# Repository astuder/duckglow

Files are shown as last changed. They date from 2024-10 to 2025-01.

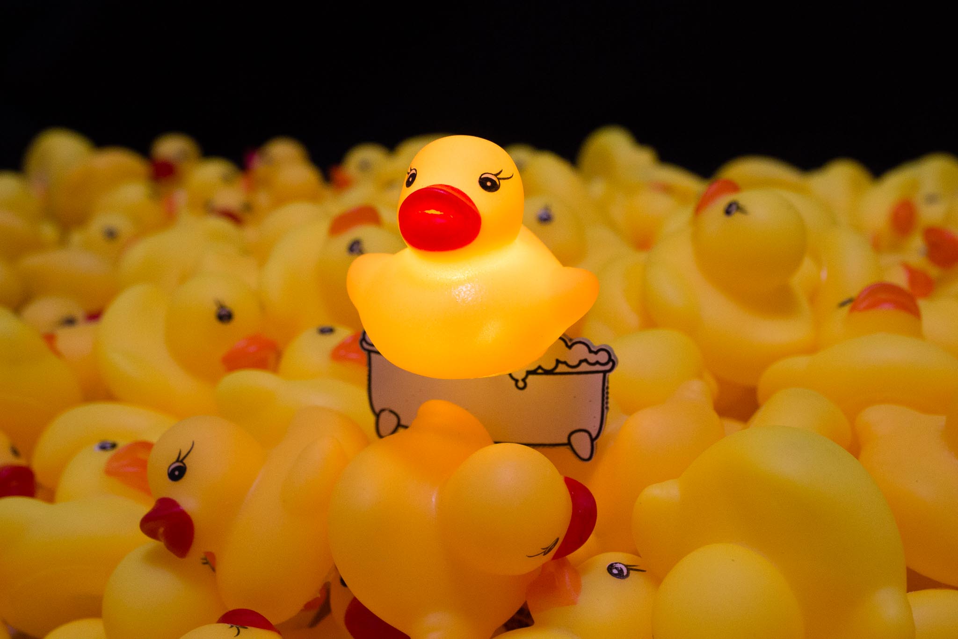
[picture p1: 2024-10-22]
pictures/duckbath.jpg

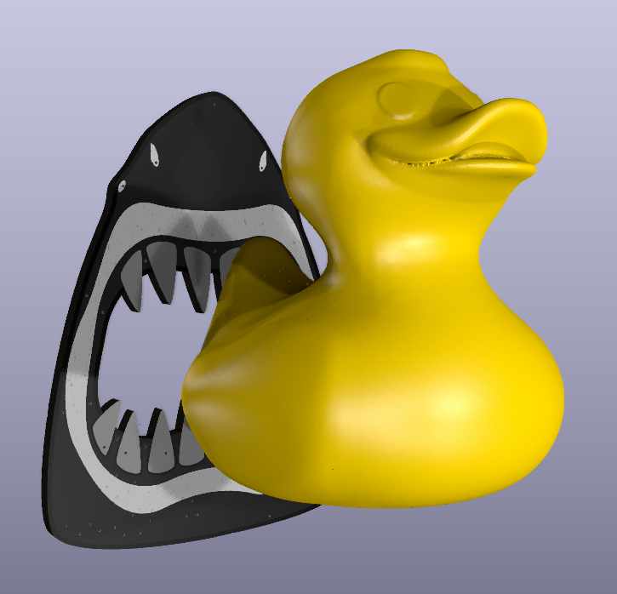
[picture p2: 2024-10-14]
pictures/duckjaws-render.png

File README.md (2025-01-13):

# duckGLOW SAO

duckGLOW is an SAO with a glowing rubber duck, lit up by an RGB or UV LED,
controllable over I2C, or like an addressable LED following the WS2812
'standard'.

See [hackaday.io](https://hackaday.io/project/198918-duckglow-sao) for more
information.

See [examples folder](./examples) for sample code to run on the SuperCon 8
SAO badge, or an Arduino.

I have a few assembled units of the duckJAWS variant for sale on [Tindie](https://www.tindie.com/products/astuder/duckjaws-sao/).

## I2C Interface

The LED of the duckGLOW SAO can be controlled over I2C. 

The SAO has four channels: red, green and blue for the duck LED, and on the
duckJAWS variant, red background lightning.

The SAO implements smooth fading configurable per channel. The LED brightness
fades between **max** and **min** value, at the chosen **speed**. If speed is 0,
the LED will steadily glow at the configured maximum. The **phase** parameter
sets the offset in the fading waveform.

The **mode** register can be used to select the interface for LED control
(auto-detect, I2C or WS2812), and to check what type of LED was detected
(RGB or UV). 

The current settings can be stored as power-on preset by writing decimal
**42** to the **save** register. The power-on presets can be factory reset by
writing **24** to the **save** register.

### I2C Address

The default I2C address of the duckGLOW SAO is *`0x6C`*. The address can be 
changed by closing solder jumpers on the back of the circuit board. 
|SJ1|SJ2|Address|
|-|-|-|
|O|O|0x6C|
|C|O|0x6D|
|O|C|0x6E|
|C|C|0x6F|

### I2C Registers

Register are accessed by first writing the 8-bit register address, and then
reading or writing register data. The register address will auto-increment
and multiple registers can be read or written within a single I2C transaction. 

For example to read the max RGB colors with an Arduino:
```
Wire.beginTransmission(0x6C);
Wire.write((uint8_t) 0xEC);
Wire.endTransmission(false);
Wire.requestFrom(0x6C, 3);
while (Wire.available()) {
  char c = Wire.read();
  Serial.println(c, HEX);
}
```

And to set the red LED to maximum brightness:

```
Wire.beginTransmission(0x6C);
Wire.write((uint8_t) 0xEC); // red led max brightness
Wire.write(0xff);
Wire.endTransmission();
Wire.beginTransmission(0x6C);
Wire.write((uint8_t) 0xF4); // animation speed
Wire.write(0x0);
Wire.endTransmission();
```

|address|name|description|
|-|-|-|
|0x00| docs | some info about the add-on |
|0xEC-EF | max | max brightness for red, green, blue and background channels |
|0xF0-F3| min | min brightness for red, green, blue and background  channels |
|0xF4-F7| speed | fading speed per channel, 0 = set LED to max value (no fading) |
|0xF8-FB| phase | offset within fading animation per channel |
|0xFC| mode | bits 0..1: LED ctrl 0=auto, 1=I2C, 2=WS2812<br>bit 4: LED type 0=RGB, 1=UV |
|0xFD| save | write 42 to save current register values as new default<br>write 24 for factory reset |
|0xFE| debug | error codes for debugging firmware |

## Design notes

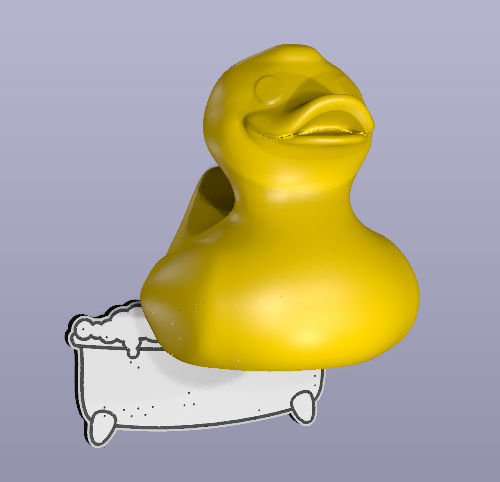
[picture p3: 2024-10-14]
pictures/duckbath-render.png

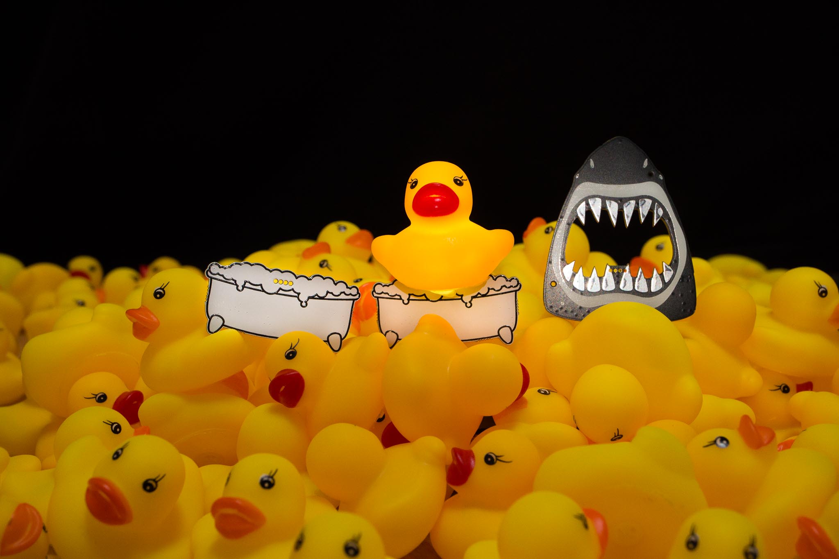
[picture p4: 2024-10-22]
pictures/duckglow-both.jpg

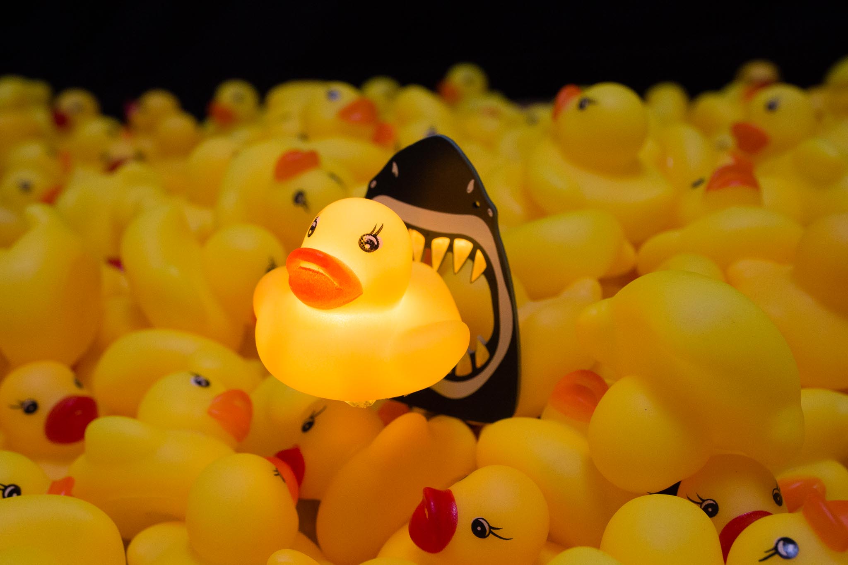
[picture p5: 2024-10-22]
pictures/duckjaws.jpg

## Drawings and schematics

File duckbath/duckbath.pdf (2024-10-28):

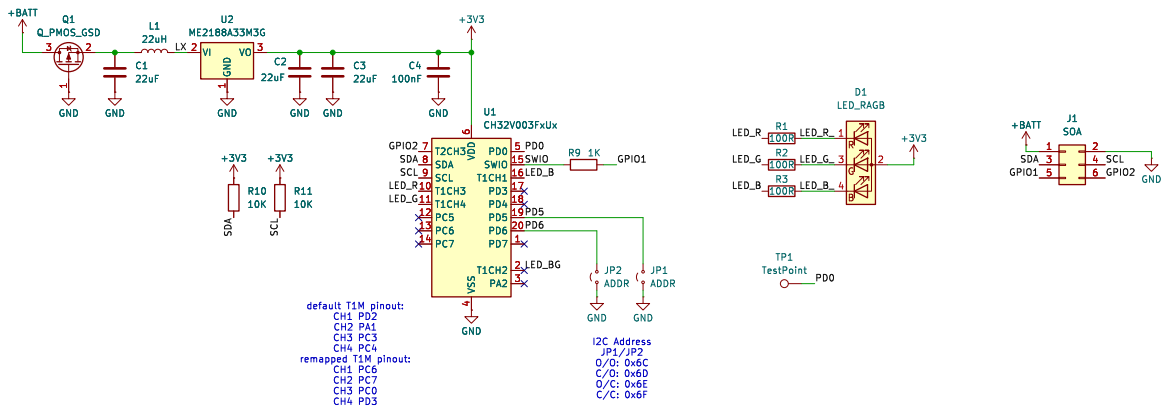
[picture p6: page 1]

6 T2CH3 7 SDA 8 SCL 9 +BATT J1 SOA

File: duckbath.kicad_sch Sheet: / þÿ©2024Adrian Studer

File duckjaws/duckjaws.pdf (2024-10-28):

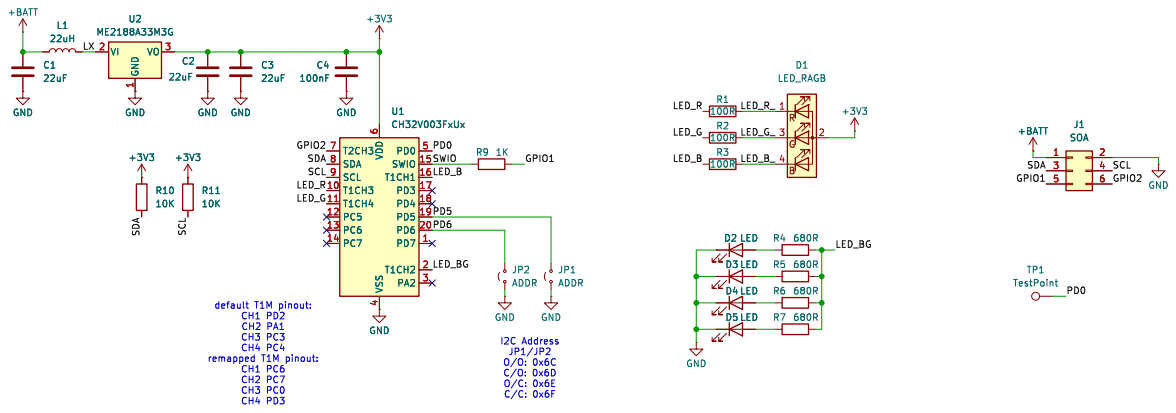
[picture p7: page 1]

1 VI 2 VO 3 GND GND
JP2 ADDR GND

File: duckjaws.kicad_sch Sheet: / þÿ©2024Adrian Studer

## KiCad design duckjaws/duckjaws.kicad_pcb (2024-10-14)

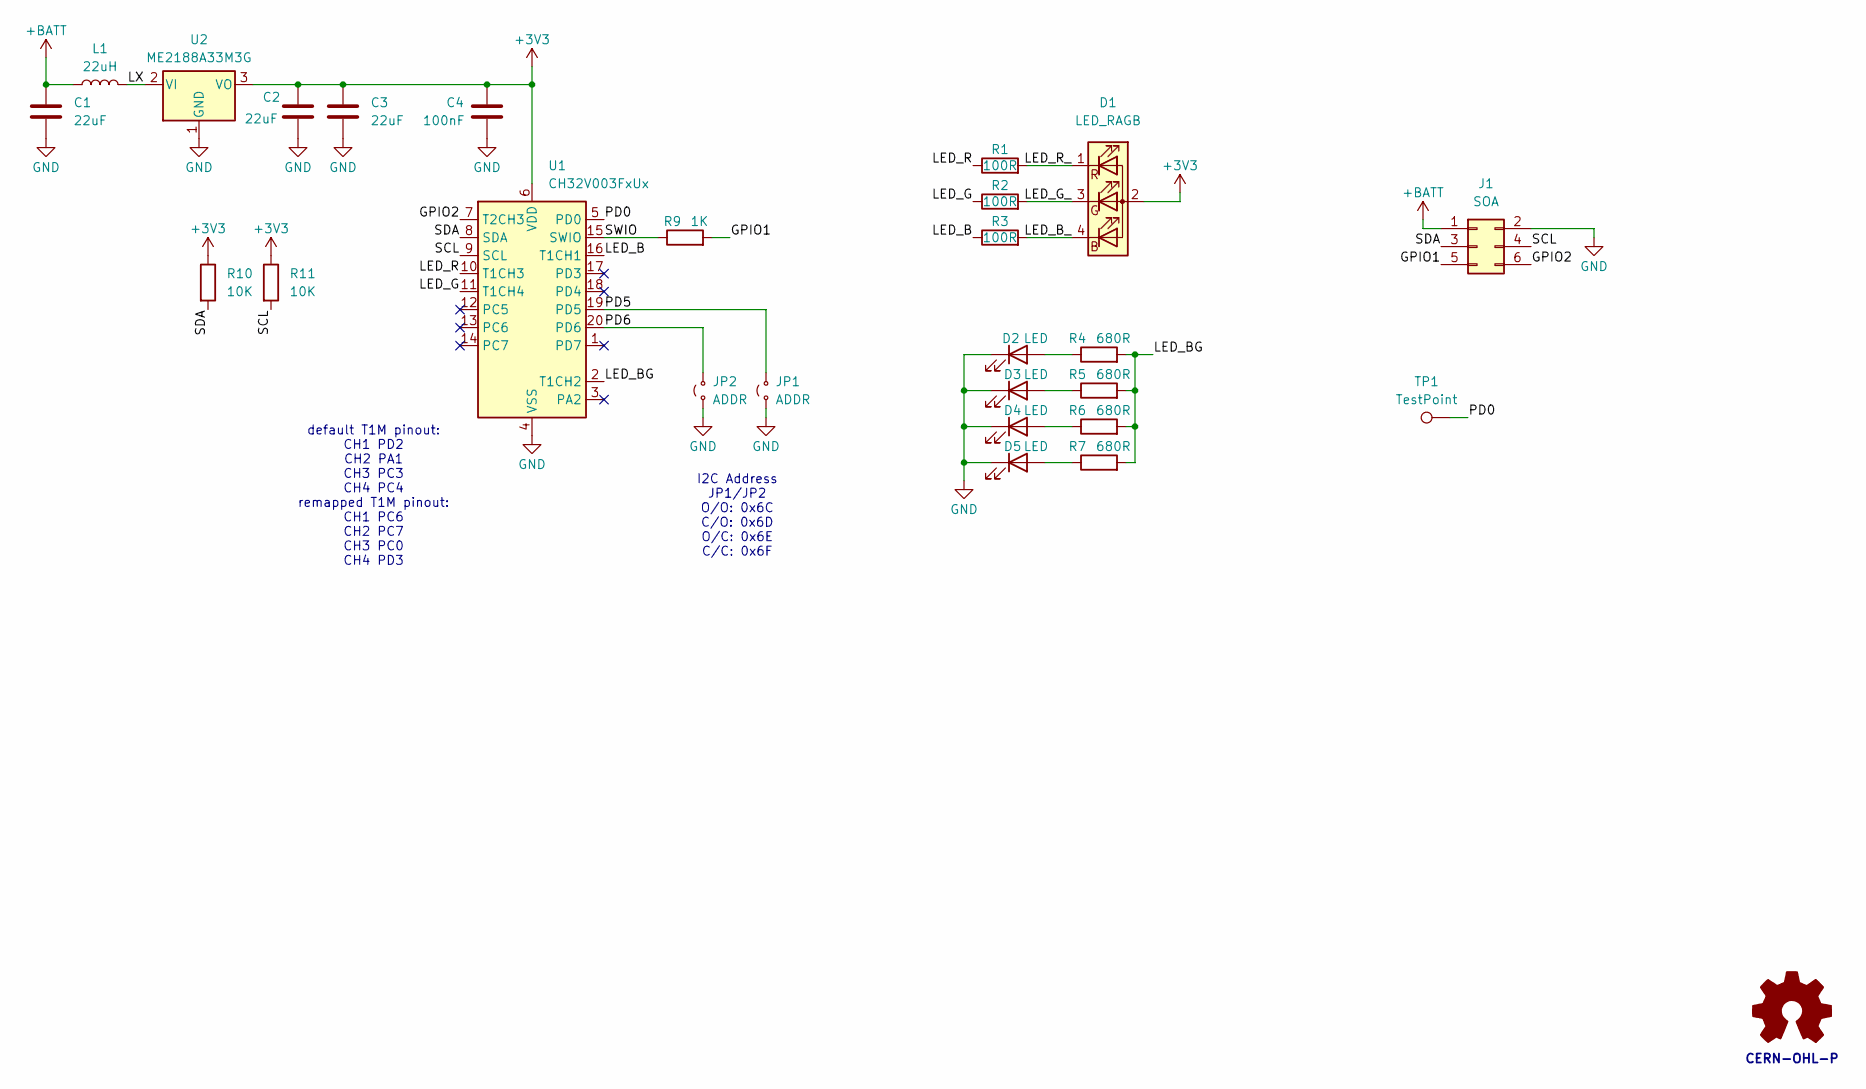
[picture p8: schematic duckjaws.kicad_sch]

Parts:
C1, C2, C3: 22uF; C_0805_2012Metric; LCSC C45783
C4: 100nF; C_0603_1608Metric; LCSC C14663
D1: LED_RAGB; LED_D5.0mm-4_RGB_single-side
D2, D3, D4, D5: LED; LED_Kingbright_APA1606_1.6x0.6mm_Horizontal; LCSC C409793
J1: SOA; PinHeader_2x03_P2.54mm_Vertical_SMD; LCSC C5160777
JP1, JP2: ADDR; SolderJumper-2_P1.3mm_Open_RoundedPad1.0x1.5mm
L1: 22uH; L_Changjiang_FNR3012S; LCSC C167732
R1, R2, R3: 100R; R_0603_1608Metric; LCSC C22775
R4, R5, R6, R7: 680R; R_0603_1608Metric; LCSC C23228
R9: 1K; R_0603_1608Metric; LCSC C21190
R10, R11: 10K; R_0603_1608Metric; LCSC C25804
TP1: TestPoint; TestPoint_Pad_D1.0mm
U1: CH32V003FxUx; QFN-20-1EP_3x3mm_P0.4mm_EP1.65x1.65mm; LCSC C5299908
U2: ME2188A33M3G; SOT-23; LCSC C111932

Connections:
+3V3: C2.1, C3.1, C4.1, D1.2 (A), R10.1, R11.1, U1.6 (VDD), U2.3 (VO)
+BATT: C1.1, J1.1, L1.1
/GPIO1: J1.5, R9.2
/GPIO2: J1.6, U1.7 (T2CH3)
/LED_B: R3.1, U1.16 (T1CH1)
/LED_BG: R4.2, R5.2, R6.2, R7.2, U1.2 (T1CH2)
/LED_B_: D1.4 (BK), R3.2
/LED_G: R2.1, U1.11 (T1CH4)
/LED_G_: D1.3 (GK), R2.2
/LED_R: R1.1, U1.10 (T1CH3)
/LED_R_: D1.1 (RK), R1.2
/LX: L1.2, U2.2 (VI)
/PD0: TP1.1, U1.5 (PD0)
/PD5: JP1.2 (B), U1.19 (PD5)
/PD6: JP2.2 (B), U1.20 (PD6)
/SCL: J1.4, R11.2, U1.9 (SCL)
/SDA: J1.3, R10.2, U1.8 (SDA)
/SWIO: R9.1, U1.15 (SWIO)
GND: C1.2, C2.2, C3.2, C4.2, D2.1 (K), D3.1 (K), D4.1 (K), D5.1 (K), J1.2, JP1.1 (A), JP2.1 (A), U1.4 (VSS), U1.21 (VSS), U2.1 (GND)
unnamed: D2.2 (A), R4.1
unnamed: D3.2 (A), R5.1
unnamed: D4.2 (A), R6.1
unnamed: D5.2 (A), R7.1

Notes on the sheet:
I2C Address JP1/JP2 O/O: 0x6C C/O: 0x6D O/C: 0x6E C/C: 0x6F
default T1M pinout: CH1 PD2 CH2 PA1 CH3 PC3 CH4 PC4 remapped T1M pinout: CH1 PC6 CH2 PC7 CH3 PC0 CH4 PD3
CERN-OHL-P

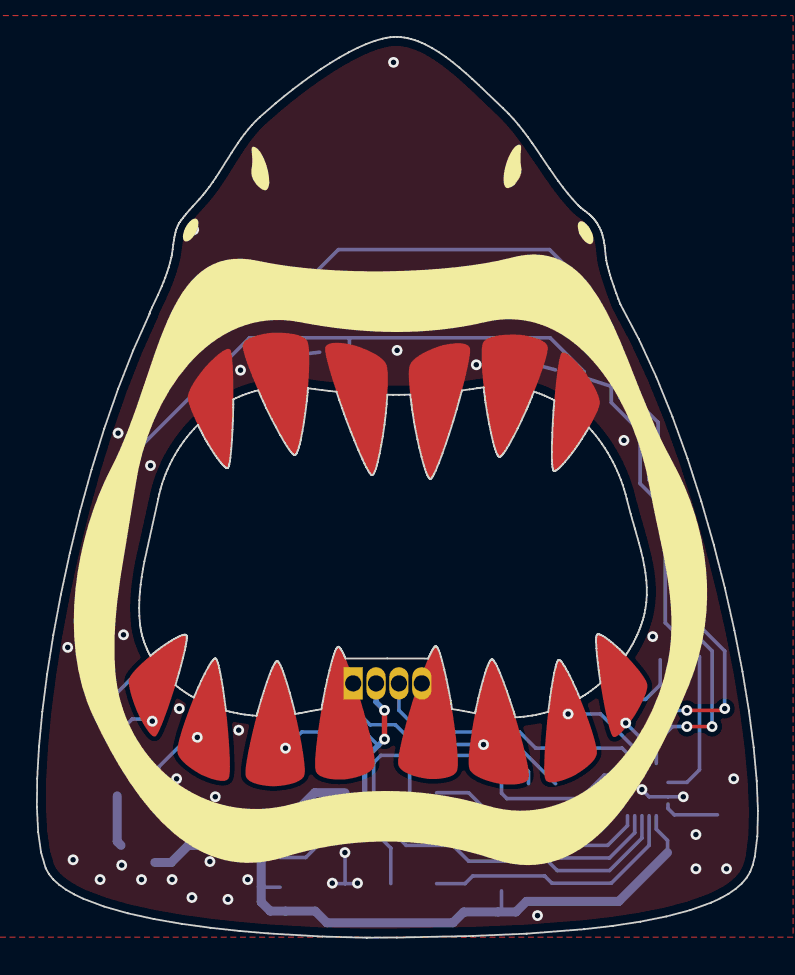
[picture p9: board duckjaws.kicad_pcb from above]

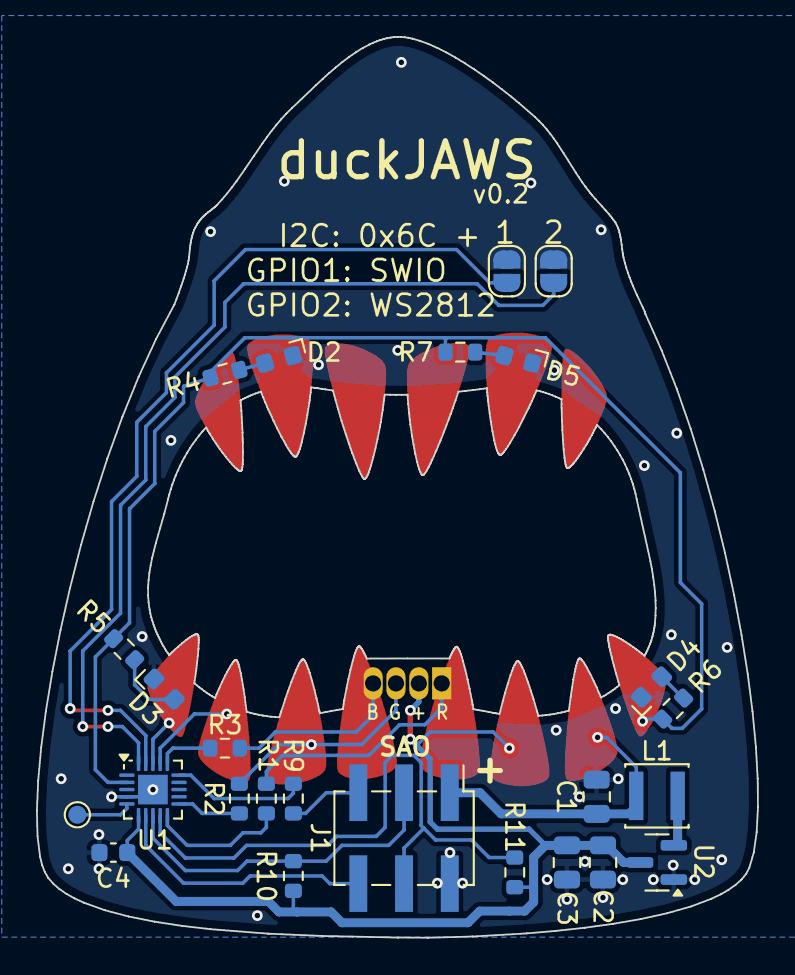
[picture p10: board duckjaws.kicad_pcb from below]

Board: 2 copper layers, 40.1 x 50.0 mm, 26 parts (25 on the bottom side), 23 nets.

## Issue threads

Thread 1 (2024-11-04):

Duck on hackaday supercon badge

marcmerlin, 2024-11-04:
Thanks for the duck, here is quick demo code for the hackaday badge

```
from machine import I2C, Pin
import time

counter = 0
overlay = [ 0, 0, 0, 0, 0, 0, 0, 0, 0, 0 ]

duck_id = 0x6c
# https://taunoerik.art/2023/08/05/programming-ch32v003/
duck_bus = None
duck_counter = 0
while not duck_bus:
    try:
        duck_bus =  which_bus_has_device_id(duck_id)[0]
    except:
        pass
    time.sleep_ms(100)
    duck_counter = duck_counter + 1
    if duck_counter > 10:
        break
if not duck_bus:
    print(f"Warning: Duck not found!")
else:
    print("F - Duck found, sending color init.")
    # https://github.com/astuder/duckglow
    duck_bus.writeto_mem(duck_id, 0xF0, bytes([0x01]))
    duck_bus.writeto_mem(duck_id, 0xF1, bytes([0x01]))
    duck_bus.writeto_mem(duck_id, 0xF2, bytes([0x01]))
    duck_bus.writeto_mem(duck_id, 0xEC, bytes([0xff]))
    duck_bus.writeto_mem(duck_id, 0xEE, bytes([0xff]))
    duck_bus.writeto_mem(duck_id, 0xED, bytes([0xff]))
    duck_bus.writeto_mem(duck_id, 0xF4, bytes([0x10]))
    duck_bus.writeto_mem(duck_id, 0xF5, bytes([0x25]))
    duck_bus.writeto_mem(duck_id, 0xF6, bytes([0x33]))

#bootLED.off()

red = 0
green = 0
blue = 0

new_red = red
new_green = green
new_blue = blue

sleep_time = 40

while True:
    if not buttonA.value():
        if not red:
            new_red = 1
            print("red Pushed")
    else:
        if red:
            new_red = 0
            print("red released")

    if not buttonB.value():
        if not green:
            new_green = 1
            print("green Pushed")
    else:
        if green:
            new_green = 0
            print("green released")

    if not buttonC.value():
        if not blue:
            new_blue = 1
            print("blue Pushed")
    else:
        if blue:
            new_blue = 0
            print("blue released")

    if duck_bus:
        if red != new_red:
            if new_red:
                # turn off blue and green
                print("red pushed to duck")
                duck_bus.writeto_mem(duck_id, 0xF0, bytes([0x80]))
                duck_bus.writeto_mem(duck_id, 0xED, bytes([0x02]))
                duck_bus.writeto_mem(duck_id, 0xEE, bytes([0x02]))
            else:
                print("duck back from red to all")
                duck_bus.writeto_mem(duck_id, 0xF0, bytes([0x00]))
                duck_bus.writeto_mem(duck_id, 0xED, bytes([0xFF]))
                duck_bus.writeto_mem(duck_id, 0xEE, bytes([0xFF]))

        if green != new_green:
            if new_green:
                # turn off green and blue
                print("green pushed to duck")
                duck_bus.writeto_mem(duck_id, 0xF1, bytes([0x80]))
                duck_bus.writeto_mem(duck_id, 0xEC, bytes([0x02]))
                duck_bus.writeto_mem(duck_id, 0xEE, bytes([0x02]))
            else:
                print("duck back from green to all")
                duck_bus.writeto_mem(duck_id, 0xF1, bytes([0x00]))
                duck_bus.writeto_mem(duck_id, 0xEC, bytes([0xFF]))
                duck_bus.writeto_mem(duck_id, 0xEE, bytes([0xFF]))

        if blue != new_blue:
            if new_blue:
                # turn off red and green
                print("blue pushed to duck")
                duck_bus.writeto_mem(duck_id, 0xF2, bytes([0x80]))
                duck_bus.writeto_mem(duck_id, 0xEC, bytes([0x02]))
                duck_bus.writeto_mem(duck_id, 0xED, bytes([0x02]))
            else:
                print("duck back from blue to all")
                duck_bus.writeto_mem(duck_id, 0xF2, bytes([0x00]))
                duck_bus.writeto_mem(duck_id, 0xEC, bytes([0xFF]))
                duck_bus.writeto_mem(duck_id, 0xED, bytes([0xFF]))

    if petal_bus:
        if new_red:
            overlay[3] = 0x80
        else:
            overlay[3] = 0

        if new_green:
            if counter % 3 == 0:
                overlay[4] = 0x80
            else:
                overlay[4] = 0
        else:
            overlay[4] = 0

        if new_blue:
            if counter % 3 == 0:
                overlay[2] = 0x80
            else:
                overlay[2] = 0
        else:
            overlay[2] = 0

        for j in range(7):
            ## see what's going on with the touch wheel
            if touchwheel_bus:
                tw = touchwheel_read(touchwheel_bus)

                if tw > 0:
                    tw = (128 - tw) % 256
                    petal = int(tw/32) + 1
                else:
                    petal = 2
                sleep_time = petal * 30

            which_leds = (1 << j)
            for i in range(1,9):
                which_leds2 = which_leds
                which_leds2 += overlay[i]
                #print (str(i) + ": " + str(which_leds2))
                petal_bus.writeto_mem(PETAL_ADDRESS, i, bytes([which_leds2]))
            time.sleep_ms(sleep_time)

    red = new_red
    green = new_green
    blue = new_blue
```

marcmerlin, 2024-11-11:
I posted my code and video here: https://github.com/marcmerlin/2024-Supercon-8-Add-On-Badge/blob/main/README.md

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

marcmerlin, 2024-11-11:
https://www.youtube.com/watch?v=yjSSQkx-x7U

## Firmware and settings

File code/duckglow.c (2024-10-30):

#include "ch32v003fun.h"
#include "i2c_slave.h"
#include "lookup.h"

#define PWM_STEPS 1024
#define PWM_SCALE 2		// left-shifts to scale 8-bit RGB to PWM resolution
#define I2C_ADDR 0x6c

// LED pins
// 	background: PA1, T1CH2, anode (+)
//	LED R: PC3, T1CH3, cathode (-)
//	LED G: PC4, T1CH4, cathode (-)
//	LED B: PD2, T1CH1, cathode (-)
#define LED_BG_PIN	PA1
#define LED_R_PIN	PC3
#define LED_G_PIN	PC4
#define LED_B_PIN	PD2

#define LED_BG_CH	2
#define LED_R_CH	3
#define LED_G_CH	4
#define LED_B_CH	1

#define WS2812_PIN	PC0
#define WS2812_CH	3

#define ERR_NONE 0
#define ERR_INVALID_PRESETS 1
#define ERR_UNLOCK_FLASH_FAILED 2
#define ERR_PRESETS_NO_CHANGE 3

uint8_t pwm_chan[] = { LED_R_CH, LED_G_CH, LED_B_CH, LED_BG_CH };

// flag to indicate detection of UV LED
volatile uint8_t uv_led = 0;

// flag to indicate I2C (0) or WS2812 (1) LED control
volatile uint8_t ws2812_mode = 0;

// setup timer 1 for PWM to drive LEDs
void t1pwm_init(void)
{
	// enable GPIOC, GPIOD and TIM1
	RCC->APB2PCENR |= 	RCC_APB2Periph_GPIOD | RCC_APB2Periph_GPIOC |
						RCC_APB2Periph_TIM1;
	
	// configure LED pins
	funPinMode(LED_BG_PIN, GPIO_CFGLR_OUT_10Mhz_AF_PP);
	funPinMode(LED_R_PIN, GPIO_CFGLR_OUT_10Mhz_AF_PP);
	funPinMode(LED_G_PIN, GPIO_CFGLR_OUT_10Mhz_AF_PP);
	funPinMode(LED_B_PIN, GPIO_CFGLR_OUT_10Mhz_AF_PP);

	// reset TIM1 to init all regs
	RCC->APB2PRSTR |= RCC_APB2Periph_TIM1;
	RCC->APB2PRSTR &= ~RCC_APB2Periph_TIM1;
	
	// CTLR1: default is up, events generated, edge align
	// SMCFGR: default clk input is CK_INT
	
	// prescaler 
	TIM1->PSC = 0x0000;
	
	// auto reload - sets period
	TIM1->ATRLR = PWM_STEPS;
	
	// reload immediately
	TIM1->SWEVGR |= TIM_UG;
	
	// enable CH1-4 output, positive pol
	TIM1->CCER |= TIM_CC1E | TIM_CC1P
				| TIM_CC2E // | TIM_CC2P background LEDs are inverted
				| TIM_CC3E | TIM_CC3P
				| TIM_CC4E | TIM_CC4P;

	// CH1+2 mode is output, PWM1 (CC1S = 00, OC1M = 110)
	TIM1->CHCTLR1 |= TIM_OC1M_2 | TIM_OC1M_1 | TIM_OC2M_2 | TIM_OC2M_1;

	// CH1+2 mode is output, PWM1 (CC1S = 00, OC1M = 110)
	TIM1->CHCTLR2 |= TIM_OC3M_2 | TIM_OC3M_1 | TIM_OC4M_2 | TIM_OC4M_1;

	// set the Capture Compare Register value to 50% initially
	TIM1->CH1CVR = 0;
	TIM1->CH2CVR = 0;
	TIM1->CH3CVR = 0;
	TIM1->CH4CVR = 0;
	
	// enable TIM1 outputs
	TIM1->BDTR |= TIM_MOE;
	
	// enable TIM1
	TIM1->CTLR1 |= TIM_CEN;
}

// set PWM for a given channel
void t1pwm_setpw(uint8_t channel, uint16_t width)
{
	switch(channel)
	{
		case 1: TIM1->CH1CVR = width; break;
		case 2: TIM1->CH2CVR = width; break;
		case 3: TIM1->CH3CVR = width; break;
		case 4: TIM1->CH4CVR = width; break;
		default: break;
	}
}

// setup timer 2 to decode WS2812 protocol
void t2cap_init(void)
{
	// configure pin as input with pull-down
	funPinMode(WS2812_PIN, GPIO_CFGLR_IN_PUPD);
	funDigitalWrite(WS2812_PIN, 0);

	// enable TIM2
	RCC->APB1PCENR |= RCC_APB1Periph_TIM2;

	// reset TIM2 to init all regs
	RCC->APB1PRSTR |= RCC_APB1Periph_TIM2;
	RCC->APB1PRSTR &= ~RCC_APB1Periph_TIM2;

	// prescaler 48MHz/(1+1) -> 12 ticks = 0.5us
	TIM2->PSC = 1;

	// TIM2CH3 is an input
	TIM2->CHCTLR2 = TIM_CC3S_0;

	// TI1 = XOR TIM2CH1,2,3, workaround to route CH3 to TI1
	TIM2->CTLR2 = TIM_TI1S;

	// Mux output of TI1 edge detector as TRGI
	// Reset mode: counter reset when TRGI goes high, counter latched on trigger
	TIM2->SMCFGR = TIM_TS_TI1F_ED + TIM_SlaveMode_Reset;

	// enable capture compare for TIM2CH3
	// set polarity of TIM2CH3 to capture timer value on falling edge
	TIM2->CCER = TIM_CC3E + TIM_CC3P;

 	// enable counter
	TIM2->CTLR1 |= TIM_CEN;
}

// address of first R/W I2C register
#define I2C_REG_START 0xec

// structure of I2C registers
struct i2c_regs_t {
	union {
		struct regs_t {
			uint8_t poem[I2C_REG_START];
			volatile uint8_t max[4];		// max LED brightness RGB,BG
			volatile uint8_t min[4];		// min LED brightness RGB,BG
			volatile uint8_t speed[4];		// LED fader speed RGB,BG
			volatile uint8_t phase[4];		// LED fader phase RGB,BG (0-255, offset into lookup-table)
			volatile uint8_t mode;			// Bits 0-1: auto/I2C/WS2812 mode, bit 4: detected LED type RGB/UV
			volatile uint8_t save;			// 42 = save current register settings to flash
			volatile uint8_t debug;			// error codes for debugging
		} regs;
		uint8_t data[255];
	};
};

// default content of I2C registers
struct i2c_regs_t i2c_regs = {
 	{
		{
			"Behold the duck.\n"
			"It does not cluck.\n"
			"A cluck it lacks.\n"
			"It quacks.\n"
			"It is specially fond\n"
			"Of a puddle or a pond.\n"
			"When it dines or sups,\n"
			"It bottoms ups.\n\n"
			"github.com/astuder/duckGLOW\n"
			"hackaday.io/project/198918-duckglow-sao\n"
			"by Adrian Studer\n"
			"\0",
			{ 80, 80, 0, 255 },		// RGB, BG max
			{ 10, 10, 0, 0 },		// RGB, BG min
			{ 2, 2, 0, 2 },			// RGB, BG speed
			{ 0, 0, 0, 128 },		// RGB, BG phase
			0, 0, 0					// mode, save, error
		}
	}
};

// callback after I2C write transaction
void on_i2c_write(uint8_t reg, uint8_t length)
{
	// enforce read-only bit for detected LED type
	if (uv_led) {
		i2c_regs.regs.mode |= 0x10;
	} else {
		i2c_regs.regs.mode &= 0xef;
	}

	// force out of ws2812 mode to reevaluate configuration
	ws2812_mode = 0;
}

// callback after I2C read 
void on_i2c_read(uint8_t reg)
{
	// do something?
}

#define PRESETS_MAGIC 0x6475636b	// "duck"
#define PRESETS_VERSION 2		// increment when modifing I2C register structure
#define PRESETS_REGS_SIZE (sizeof(i2c_regs.regs) - sizeof(i2c_regs.regs.poem) - 2)	// exclude save and error regs
#define PRESETS_ADDR 0x08003fc0	// points to page 255 in flash, we hope our code will never use that much flash

// structure of configuration data saved to flash
typedef struct {
	union {
		struct fields_t {
			uint32_t magic;
			uint8_t version;
			char regs[PRESETS_REGS_SIZE];
		} fields;
		volatile uint32_t raw[16];
	};
} presets_t;

presets_t *flash_presets = (presets_t*) PRESETS_ADDR;

// load register settings from flash
bool presets_load(void)
{
	i2c_regs.regs.debug = ERR_NONE;
	// verify that magic and version do match
	if (flash_presets->fields.magic != PRESETS_MAGIC || flash_presets->fields.version != PRESETS_VERSION) {
		i2c_regs.regs.debug = ERR_INVALID_PRESETS;	// presets invalid
		return 0;
	}

	// initialize I2C registers from flash
	for (uint8_t i=0; i<PRESETS_REGS_SIZE; i++) {
		i2c_regs.data[I2C_REG_START+i] = flash_presets->fields.regs[i];
	}
	return 1;
}

// save current register settings to flash
bool presets_save(void)
{
	i2c_regs.regs.debug = ERR_NONE;
	// fill in presets structure
	presets_t p;
	for (uint8_t i=0; i<16; i++) {
		p.raw[i] = 0;
	}
	p.fields.magic = PRESETS_MAGIC;
	p.fields.version = PRESETS_VERSION;
	for (uint8_t i=0; i<PRESETS_REGS_SIZE; i++) {
		p.fields.regs[i] = i2c_regs.data[I2C_REG_START+i];
	}

	// check if writing to flash is needed, prevents excessive wear
	uint8_t diff = 0;
	for (uint8_t i=0; i<16; i++) {
		if (p.raw[i] != flash_presets->raw[i]) {
			diff++;
		}
	}
	if (diff == 0) {
		// presets already up-to-date, still report success
		i2c_regs.regs.debug = ERR_PRESETS_NO_CHANGE;
		return 1;
	}

	// unlock flash
	FLASH->KEYR = 0x45670123;
	FLASH->KEYR = 0xCDEF89AB;
	FLASH->MODEKEYR = 0x45670123;
	FLASH->MODEKEYR = 0xCDEF89AB;
	if (FLASH->CTLR & 0x8080) {
		// failed to unlock flash
		i2c_regs.regs.debug = ERR_UNLOCK_FLASH_FAILED;
		return 0;
	}

	// erase page
	FLASH->CTLR = CR_PAGE_ER;
	FLASH->ADDR = (intptr_t) PRESETS_ADDR;
	FLASH->CTLR = CR_STRT_Set | CR_PAGE_ER;
	while (FLASH->STATR & FLASH_STATR_BSY);

	// write page
	FLASH->CTLR = CR_PAGE_PG;
	FLASH->CTLR = CR_BUF_RST | CR_PAGE_PG;
	FLASH->ADDR = (intptr_t) PRESETS_ADDR;
	while (FLASH->STATR & FLASH_STATR_BSY);
	for (uint8_t i=0; i<16; i++) {
		flash_presets->raw[i] = p.raw[i]; 				// write to the memory
		FLASH->CTLR = CR_PAGE_PG | FLASH_CTLR_BUF_LOAD; // load the buffer
		while (FLASH->STATR & FLASH_STATR_BSY);  		// wait for completion
	}
	FLASH->CTLR = CR_PAGE_PG | CR_STRT_Set;
	while (FLASH->STATR & FLASH_STATR_BSY);

	// lock flash
	FLASH->CTLR = CR_LOCK_Set;

	return 1;
}

bool factory_reset() {
	i2c_regs.regs.debug = ERR_NONE;
	// erase custom presets from flash
	if (flash_presets->fields.magic == PRESETS_MAGIC) {
		// unlock flash
		FLASH->KEYR = 0x45670123;
		FLASH->KEYR = 0xCDEF89AB;
		FLASH->MODEKEYR = 0x45670123;
		FLASH->MODEKEYR = 0xCDEF89AB;
		if (FLASH->CTLR & 0x8080) {
			// failed to unlock flash
			i2c_regs.regs.debug = ERR_UNLOCK_FLASH_FAILED;
			return 0;
		}

		// erase page
		FLASH->CTLR = CR_PAGE_ER;
		FLASH->ADDR = (intptr_t) PRESETS_ADDR;
		FLASH->CTLR = CR_STRT_Set | CR_PAGE_ER;
		while (FLASH->STATR & FLASH_STATR_BSY);

		// lock flash
		FLASH->CTLR = CR_LOCK_Set;
	}

	// force reset after 1 second by enabling watchdog
	IWDG->CTLR = 0x5555;
	IWDG->PSCR = IWDG_Prescaler_128;
	IWDG->CTLR = 0x5555;
	IWDG->RLDR = 0xff & 0xfff;
	IWDG->CTLR = 0xCCCC;
	IWDG->CTLR = 0xAAAA;
	while(1);
}

int main()
{
	SystemInit();
	funGpioInitAll();

	// enable pins routed test point and to lower right teeth, set them all low
	funPinMode(PD0, GPIO_CFGLR_OUT_10Mhz_PP);	// test point
	funPinMode(PD3, GPIO_CFGLR_OUT_10Mhz_PP);	// tooth, 2nd from right
	funPinMode(PD4, GPIO_CFGLR_OUT_10Mhz_PP);	// tooth, lower right 
	funDigitalWrite(PD0, 0);
	funDigitalWrite(PD3, 0);
	funDigitalWrite(PD4, 0);

	// set I2C address based on jumper configuration
	// PD5 connected to GND adds 1 to I2C_ADDR
	// PD6 connected to GND adds 2 to I2C_ADDR
	funPinMode(PD5, GPIO_CFGLR_IN_PUPD);
	funPinMode(PD6, GPIO_CFGLR_IN_PUPD);
	funDigitalWrite(PD5, 1);
	funDigitalWrite(PD6, 1);
	Delay_Ms(100);
	uint8_t i2c_addr = I2C_ADDR + (((funDigitalRead(PD6) << 1) + funDigitalRead(PD5)) ^ 3);

	// detect RGB LED on R pin with pull-down reads highish
	uv_led = 0;
	funPinMode(LED_R_PIN, GPIO_CFGLR_IN_PUPD);
	funDigitalWrite(LED_R_PIN, 1);	// start high to use 150mV schmitt trigger hystersis to over benefit
	Delay_Ms(10);
	funDigitalWrite(LED_R_PIN, 0);
	Delay_Ms(10);
	if (funDigitalRead(LED_R_PIN) == 0) {
		uv_led = 1;
	}

	if (uv_led) {
		// No RGB LED connected -> hard coded default I2C settings for for UV duck
		i2c_regs.regs.max[2] = 255;
		i2c_regs.regs.min[2] = 0;
		i2c_regs.regs.speed[2] = 2;
	}

	// load presets from flash
	presets_load();

	// override uv bit
	if (uv_led) {
		i2c_regs.regs.mode |= 0x10;	// set bit to indicate UV LED
	}

	// setup I2C	
	funPinMode(PC1, GPIO_CFGLR_OUT_10Mhz_AF_OD);
	funPinMode(PC2, GPIO_CFGLR_OUT_10Mhz_AF_OD);
	SetupI2CSlave(i2c_addr, i2c_regs.data, sizeof(i2c_regs.data), on_i2c_write, on_i2c_read, false);

	// init TIM1 and related GPIO for PWM
	t1pwm_init();

	// init TIM2 for input capture mode
	t2cap_init();

	uint16_t idx[4] = { 0, 0, 0, 0 };
	uint16_t pos[4] = { i2c_regs.regs.phase[0]<<2, i2c_regs.regs.phase[1]<<2, i2c_regs.regs.phase[2]<<2, i2c_regs.regs.phase[3]<<2 };
	uint32_t val;

	while(1)
	{
		if (i2c_regs.regs.save == 42) {
			i2c_regs.regs.save = 0;
			presets_save();
		}

		if (i2c_regs.regs.save == 24) {
			i2c_regs.regs.save = 0;
			factory_reset();
		}

		uint8_t led_mode = i2c_regs.regs.mode & 0x03;
		if (led_mode == 0) {
			// auto-detect WS2812 mode if there's a pulse <2us)
			if (TIM2->INTFR & TIM_CC3IF) {
				uint16_t cv = TIM2->CH3CVR;
				if (cv > 0 && cv < 48) {
					ws2812_mode = 1;
				}
			}
		} else if (led_mode == 2) {
			// configured in ws2812 mode
			ws2812_mode = 1;
		} else {
			// configured in I2C mode
			ws2812_mode = 0;
		}

		if (ws2812_mode) {
			// WS2812 timing
			// datasheet:
			// 0: 0.35us / 0.8us
			// 1: 0.7us / 0.6us
			// 1.25us +/- 0.6us per bit
			// latch: > 50us
			// https://wp.josh.com/2014/05/13/ws2812-neopixels-are-not-so-finicky-once-you-get-to-know-them/
			// 0: 0.2-0.5us pulse
			// 1: >0.5us pulse
			// latch: > 6us low
			// simiplified
			// if pulse <= 0.5us: 0, else: 1
			// if low for more than 6us, latch
			while (ws2812_mode)
			{
				uint32_t low_time;
				uint32_t color;
				uint8_t end_pulse;

				end_pulse = 0;
				color = 0;

				// wait for first pulse
				while (!(TIM2->INTFR & TIM_CC3IF)) {
					if(ws2812_mode == 0) {
						goto skip_ws2812;	// exiting ws2812 mode. oh no! a goto! :)
					}
				};

				// prevent disruption until end pulse or invalid bit
				__disable_irq();

				while (!end_pulse)
				{
					// read pulse length
					uint16_t p = TIM2->CH3CVR;
					if (p < 12) {
						// pulse is T0H length (less than approx. 0.5us)
						color <<= 1;
					} else if (p < 48) {
						// pulse is T1H length
						color = (color << 1) | 1;
					} else {
						// treat pulse > 2us as error
						break;
					}

					// wait for next pulse
					low_time = 0;
					while (!(TIM2->INTFR & TIM_CC3IF))
					{
						low_time++;
						if (low_time == 30) {
							// no pulse for 6+ us, end of transmission
							end_pulse = 1;
							break;
						}
					}
				}

				__enable_irq();

				if (end_pulse) {
					// latch color into LEDs
					// final GRB tripplet is duck, final byte (blue) of second-to-last tripplet is background
					t1pwm_setpw(pwm_chan[2], (color & 0xff) << PWM_SCALE);	// duck blue
					color >>= 8;
					t1pwm_setpw(pwm_chan[0], (color & 0xff) << PWM_SCALE);	// duck red
					color >>= 8;
					t1pwm_setpw(pwm_chan[1], (color & 0xff) << PWM_SCALE);	// duck green
					color >>= 8;
					t1pwm_setpw(pwm_chan[3], (color & 0xff) << PWM_SCALE);	// background
				}

				skip_ws2812:
			}
		} else {
			for (uint8_t ch = 0; ch < 4; ch++)
			{
				if (i2c_regs.regs.speed[ch] == 0)
				{
					// use fixed color if speed = 0
					val = i2c_regs.regs.max[ch] << PWM_SCALE;
					if (val >= PWM_STEPS)
					{
						val = PWM_STEPS-1;
					}
					t1pwm_setpw(pwm_chan[ch], val);
				}
				else
				{
					// do sine fading if speed is set
					uint16_t max = i2c_regs.regs.max[ch] << PWM_SCALE;
					uint16_t min = i2c_regs.regs.min[ch] << PWM_SCALE;
					val = ((((uint32_t) sine[pos[ch]]) * (max - min)) >> 16) + min;
					if (val >= PWM_STEPS)
					{
						val = PWM_STEPS-1;
					}
					t1pwm_setpw(pwm_chan[ch], val);
					idx[ch] += i2c_regs.regs.speed[ch];
					if (idx[ch] >= sine_size)
					{
						idx[ch] -= sine_size;
					}
					pos[ch] = idx[ch] + (i2c_regs.regs.phase[ch]<<2);
					if (pos[ch] >= sine_size)
					{
						pos[ch] -= sine_size;
					}
				}
			}
		}

		Delay_Ms(20);
	}
}

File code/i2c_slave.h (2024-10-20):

/*
 * Single-File-Header for using the I2C peripheral in slave mode
 *
 * MIT License
 *
 * Copyright (c) 2024 Renze Nicolai
 *
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
 * THE SOFTWARE IS PROVIDED "AS IS", WITHOUT WARRANTY OF ANY KIND, EXPRESS OR
 * IMPLIED, INCLUDING BUT NOT LIMITED TO THE WARRANTIES OF MERCHANTABILITY,
 * FITNESS FOR A PARTICULAR PURPOSE AND NONINFRINGEMENT. IN NO EVENT SHALL THE
 * AUTHORS OR COPYRIGHT HOLDERS BE LIABLE FOR ANY CLAIM, DAMAGES OR OTHER
 * LIABILITY, WHETHER IN AN ACTION OF CONTRACT, TORT OR OTHERWISE, ARISING FROM,
 * OUT OF OR IN CONNECTION WITH THE SOFTWARE OR THE USE OR OTHER DEALINGS IN THE
 * SOFTWARE.
 */

#ifndef __I2C_SLAVE_H
#define __I2C_SLAVE_H

#include "ch32v003fun.h"
#include <stdint.h>
#include <stdio.h>
#include <stdbool.h>

// read-only register range, writes will be ignored
#define RO_START    0
#define RO_END      0xeb

typedef void (*i2c_write_callback_t)(uint8_t reg, uint8_t length);
typedef void (*i2c_read_callback_t)(uint8_t reg);

struct _i2c_slave_state {
    uint8_t first_write;
    uint8_t offset;
    uint8_t position;
    volatile uint8_t* volatile registers1;
    uint8_t size1;
    volatile uint8_t* volatile registers2;
    uint8_t size2;
    i2c_write_callback_t write_callback1;
    i2c_read_callback_t read_callback1;
    bool read_only1;
    i2c_write_callback_t write_callback2;
    i2c_read_callback_t read_callback2;
    bool read_only2;
    bool writing;
    bool address2matched;
} i2c_slave_state;

void SetupI2CSlave(uint8_t address, volatile uint8_t* registers, uint8_t size, i2c_write_callback_t write_callback, i2c_read_callback_t read_callback, bool read_only) {
    i2c_slave_state.first_write = 1;
    i2c_slave_state.offset = 0;
    i2c_slave_state.position = 0;
    i2c_slave_state.registers1 = registers;
    i2c_slave_state.size1 = size;
    i2c_slave_state.registers2 = NULL;
    i2c_slave_state.size2 = 0;
    i2c_slave_state.write_callback1 = write_callback;
    i2c_slave_state.read_callback1 = read_callback;
    i2c_slave_state.read_only1 = read_only;
    i2c_slave_state.write_callback2 = NULL;
    i2c_slave_state.read_callback2 = NULL;
    i2c_slave_state.read_only2 = false;

    // Enable I2C1
    RCC->APB1PCENR |= RCC_APB1Periph_I2C1;

    // Reset I2C1 to init all regs
    RCC->APB1PRSTR |= RCC_APB1Periph_I2C1;
    RCC->APB1PRSTR &= ~RCC_APB1Periph_I2C1;

    I2C1->CTLR1 |= I2C_CTLR1_SWRST;
    I2C1->CTLR1 &= ~I2C_CTLR1_SWRST;

    // Set module clock frequency
    uint32_t prerate = 2000000; // I2C Logic clock rate, must be higher than the bus clock rate
    I2C1->CTLR2 |= (FUNCONF_SYSTEM_CORE_CLOCK/prerate) & I2C_CTLR2_FREQ;

    // Enable interrupts
    I2C1->CTLR2 |= I2C_CTLR2_ITBUFEN | I2C_CTLR2_ITEVTEN | I2C_CTLR2_ITERREN;

    NVIC_EnableIRQ(I2C1_EV_IRQn); // Event interrupt
    NVIC_SetPriority(I2C1_EV_IRQn, 2 << 4);
    NVIC_EnableIRQ(I2C1_ER_IRQn); // Error interrupt
    NVIC_SetPriority(I2C1_ER_IRQn, 2 << 4);

    // Set clock configuration
    uint32_t clockrate = 1000000; // I2C Bus clock rate, must be lower than the logic clock rate
    I2C1->CKCFGR = ((FUNCONF_SYSTEM_CORE_CLOCK/(3*clockrate))&I2C_CKCFGR_CCR) | I2C_CKCFGR_FS; // Fast mode 33% duty cycle
    //I2C1->CKCFGR = ((FUNCONF_SYSTEM_CORE_CLOCK/(25*clockrate))&I2C_CKCFGR_CCR) | I2C_CKCFGR_DUTY | I2C_CKCFGR_FS; // Fast mode 36% duty cycle
    //I2C1->CKCFGR = (FUNCONF_SYSTEM_CORE_CLOCK/(2*clockrate))&I2C_CKCFGR_CCR; // Standard mode good to 100kHz

    // Set I2C address
    I2C1->OADDR1 = address << 1;
    I2C1->OADDR2 = 0;

    // Enable I2C
    I2C1->CTLR1 |= I2C_CTLR1_PE;

    // Acknowledge bytes when they are received
    I2C1->CTLR1 |= I2C_CTLR1_ACK;
}

void SetupSecondaryI2CSlave(uint8_t address, volatile uint8_t* registers, uint8_t size, i2c_write_callback_t write_callback, i2c_read_callback_t read_callback, bool read_only) {
    if (address > 0) {
        I2C1->OADDR2 = (address << 1) | 1;
        i2c_slave_state.registers2 = registers;
        i2c_slave_state.size2 = size;
        i2c_slave_state.write_callback2 = write_callback;
        i2c_slave_state.read_callback2 = read_callback;
        i2c_slave_state.read_only2 = read_only;
    } else {
        I2C1->OADDR2 = 0;
    }
}

void SetI2CSlaveReadOnly(bool read_only) {
    i2c_slave_state.read_only1 = read_only;
}

void SetSecondaryI2CSlaveReadOnly(bool read_only) {
    i2c_slave_state.read_only2 = read_only;
}

void I2C1_EV_IRQHandler(void) __attribute__((interrupt));
void I2C1_EV_IRQHandler(void) {
    uint16_t STAR1, STAR2 __attribute__((unused));
    STAR1 = I2C1->STAR1;
    STAR2 = I2C1->STAR2;

    if (STAR1 & I2C_STAR1_ADDR) { // Start event
        i2c_slave_state.first_write = 1; // Next write will be the offset
        i2c_slave_state.position = i2c_slave_state.offset; // Reset position
        i2c_slave_state.address2matched = !!(STAR2 & I2C_STAR2_DUALF);
    }

    if (STAR1 & I2C_STAR1_RXNE) { // Write event
        if (i2c_slave_state.first_write) { // First byte written, set the offset
            i2c_slave_state.offset = I2C1->DATAR;
            i2c_slave_state.position = i2c_slave_state.offset;
            i2c_slave_state.first_write = 0;
            i2c_slave_state.writing = false;
        } else { // Normal register write
            i2c_slave_state.writing = true;
            if (i2c_slave_state.position >= RO_START && i2c_slave_state.position <= RO_END) {
                // ignore writes within read-only range
            } else if (i2c_slave_state.address2matched) {
                if (i2c_slave_state.position < i2c_slave_state.size2 && !i2c_slave_state.read_only2) {
                    i2c_slave_state.registers2[i2c_slave_state.position] = I2C1->DATAR;
                    i2c_slave_state.position++;
                }
            } else {
                if (i2c_slave_state.position < i2c_slave_state.size1 && !i2c_slave_state.read_only1) {
                    i2c_slave_state.registers1[i2c_slave_state.position] = I2C1->DATAR;
                    i2c_slave_state.position++;
                }
            }
        }
    }
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

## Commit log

2024-10-19 add phase to LED fader registers
2024-10-19 auto-detect RGB or UV LED configuration
2024-10-27 implement WS2812 LED control
2024-10-27 prevent flash wear when repeatedly saving unchanged presets
    [duckglow.c]
2024-10-28 readme with detailed I2C documentation
2024-10-28 add PDFs of schematics
2024-10-28 replace register documentation with links to github and hackaday.io
    [duckglow.c]
2024-10-29 add factory reset function, fix saving of presets
    [duckglow.c]
2024-10-29 clarify description of some I2C registers
2024-10-30 add sketch to test duck feature from an Arduino
2024-11-03 add demo for I2C led control
